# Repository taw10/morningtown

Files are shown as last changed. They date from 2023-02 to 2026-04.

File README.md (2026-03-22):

MorningTown: A silent alarm clock
=================================

Description
-----------

MorningTown is a silent alarm clock system based on a Raspberry Pi Pico.

At 7:15am, it lights a single green LED.  At 8am, it additionally lights a red
LED.  Around midday, it turns them both off.  Apart from an over-engineered
configuration system, it does literally nothing else.

Why???
------

You are supposed to get out of bed if you wake up and see the green light, or
perhaps doze until you see the red light as well.  If no lights are on, go
back to sleep.

Huh??
-----

[Awareness of the exact time is bad for your sleep](https://www.techradar.com/health-fitness/mattresses/clock-watching-could-be-killing-your-sleep-why-clocks-have-no-place-in-the-bedroom).

If you're having trouble getting to sleep, seeing the time will add stress
and make it even harder to sleep.  Similarly, knowing that your alarm will go off
shortly can prevent you from relaxing in the morning, and grabbing a valuable
few minutes' extra sleep.

MorningTown reduces information about the time down to a simple signal to say
either "Go back to sleep" or "Get up if you're ready".

In contrast to a clock radio or "artificial sunrise" lamp, there is no danger
of disturbing any other beings who share the room and may run on different
schedules.

I still have a number of questions
----------------------------------

Obviously, you should set an audible alarm clock for important wake-up calls.

Hardware
--------

The Pi Pico's real-time clock loses time when power is removed, so MorningTown
needs either a separate battery-backed RTC module, or to synchronise itself
using NTP on each startup.

### PCB with real-time clock and battery backup

Send the circuit board design in the `pcb` folder
([KiCad](https://www.kicad.org/) format) to your manufacturer of choice.
I have been using [Aisler](https://aisler.net/).

### Cheap and cheerful option

Solder red and green LEDs to GPIOs 22 and 21 respectively of a Raspberry Pi
Pico W, each with a 1.5 kOhm series resistor (you won't need much brightness).
There is a ground pad conveniently placed between these two pins.

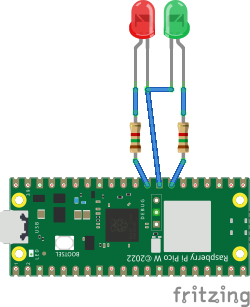
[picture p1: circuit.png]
Circuit diagram
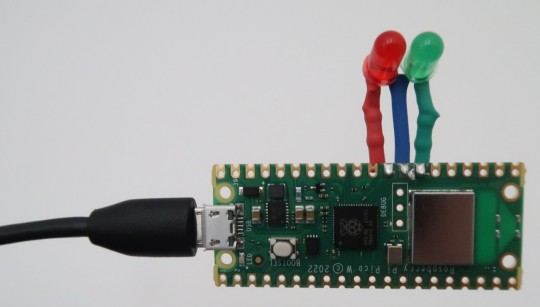
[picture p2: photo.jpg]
    

You can use other GPIOs if you prefer - see below for configuration
instructions.

Firmware
--------

Edit `compile` to set the path to the [Pico SDK](https://github.com/raspberrypi/pico-sdk),
as well as your WLAN name and password if you are using a Pico W.

The changeover days for daylight savings are hard-coded for Europe (the last
Sundays of March and October).  Unfortunately, a full local time library is far
too big to fit on the Pico, so you will have to figure out the logic yourself
for other time zones.

Run `compile`, then copy `build/morningtown.uf2` to the Pico.

Operation
---------

Connect the Pico to any USB power supply.

When the (optional) test button is held, the LEDs indicate as follows:
* Red: NTP synchronised if applicable, otherwise always on.
* Green: RTC time OK (regardless of source).
* Board LED: WLAN connected if applicable, otherwise always on.

Licence
-------

MorningTown is based on a heavily modified version of one of the Pico SDK
examples (picow-ntp-client), copyright (c) 2022 Raspberry Pi (Trading) Ltd.,
under the BSD 3-clause licence.

MorningTown is free software: you can redistribute it and/or modify it under the
terms of the GNU General Public License as published by the Free Software
Foundation, either version 3 of the License, or (at your option) any later
version.

MorningTown is distributed in the hope that it will be useful, but WITHOUT ANY
WARRANTY; without even the implied warranty of MERCHANTABILITY or FITNESS FOR A
PARTICULAR PURPOSE.  See the GNU General Public License for more details.

You should have received a copy of the GNU General Public License along with
MorningTown.  If not, see <http://www.gnu.org/licenses/>.

About the name
--------------

It's like a railway signal for your sleep:

> Somewhere there is sunshine  
> Somewhere there is day  
> Somewhere there is Morning town  
> Many miles away

- [Malvina Reynolds](https://en.wikipedia.org/wiki/Morningtown_Ride)

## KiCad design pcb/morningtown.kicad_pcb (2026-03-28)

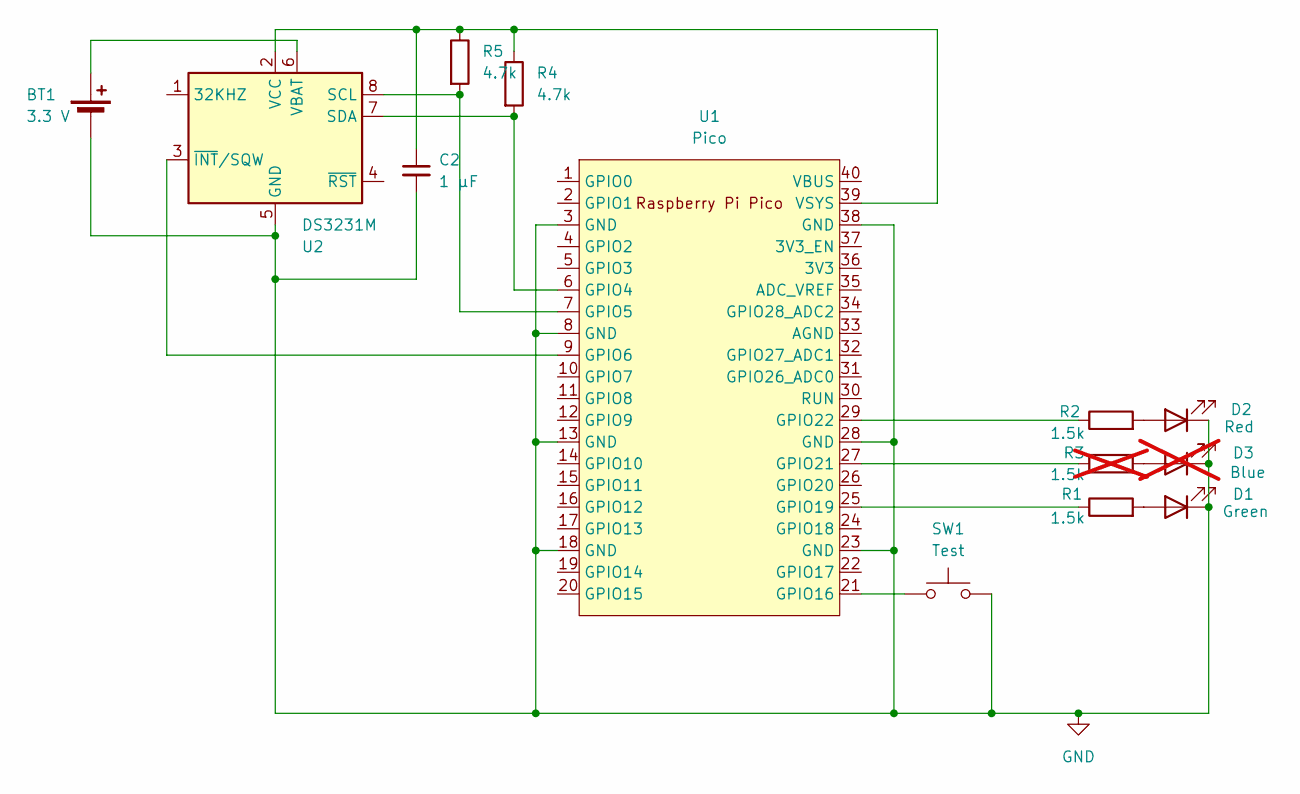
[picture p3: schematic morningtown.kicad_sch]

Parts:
BT1: 3.3 V; BatteryHolder_Keystone_3001_1x12mm
C2: 1 µF; C_0805_2012Metric_Pad1.18x1.45mm_HandSolder
D1: Green; LED_D5.0mm
D2: Red; LED_D5.0mm
D3: Blue; LED_D3.0mm; not fitted
R1, R2: 1.5k; R_0805_2012Metric_Pad1.20x1.40mm_HandSolder
R3: 1.5k; R_0805_2012Metric_Pad1.20x1.40mm_HandSolder; not fitted
R4, R5: 4.7k; R_0805_2012Metric_Pad1.20x1.40mm_HandSolder
SW1: Test; SW_PUSH_6mm
U1: Pico; RPi_Pico_W
U2: DS3231M; SOIC-8_3.9x4.9mm_P1.27mm

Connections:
GND: BT1.2 (-), C2.2, D1.1 (K), D2.1 (K), D3.1 (K), SW1.2, U1.3 (GND), U1.8 (GND), U1.13 (GND), U1.18 (GND), U1.23 (GND), U1.28 (GND), U1.38 (GND), U2.5 (GND)
unnamed: BT1.1 (+), U2.6 (VBAT)
unnamed: D1.2 (A), R1.2
unnamed: D2.2 (A), R2.2
unnamed: D3.2 (A), R3.2
unnamed: R4.2, U1.6 (GPIO4), U2.7 (SDA)
unnamed: R5.2, U1.7 (GPIO5), U2.8 (SCL)
unnamed: U1.9 (GPIO6), U2.3 (~INT/SQW)
unnamed: SW1.1, U1.21 (GPIO16)
unnamed: R1.1, U1.25 (GPIO19)
unnamed: R3.1, U1.27 (GPIO21)
unnamed: R2.1, U1.29 (GPIO22)
unnamed: C2.1, R4.1, R5.1, U1.39 (VSYS), U2.2 (VCC)

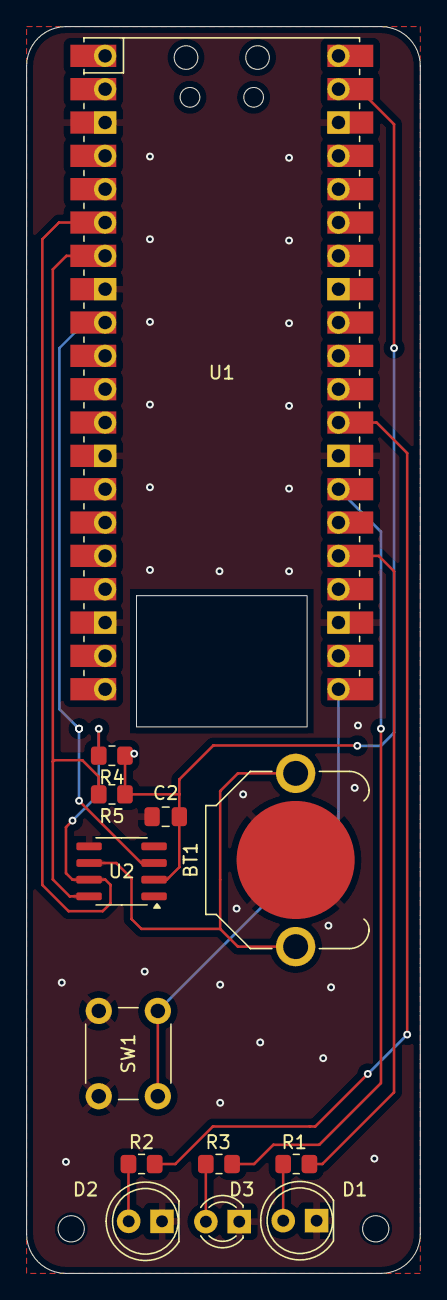
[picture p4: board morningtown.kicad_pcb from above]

Board: 2 copper layers, 30.0 x 95.0 mm, 15 parts (0 on the bottom side), 13 nets.

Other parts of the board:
FrontL: MountingHole_2mm
FrontR: MountingHole_2mm

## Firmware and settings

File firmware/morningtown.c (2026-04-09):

/*
 * morningtown.c
 *
 * Silent alarm clock
 *
 * Copyright © 2023 Thomas White <taw@physics.org>
 *
 * This file is part of MorningTown
 *
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
 */

#include <pico/stdlib.h>
#include <hardware/rtc.h>
#include <hardware/watchdog.h>
#include <hardware/pwm.h>
#include <time.h>
#include <stdio.h>

#ifdef PICO_W
#include <pico/cyw43_arch.h>
#endif

#include "ntp_client.h"
#include "terminal.h"
#include "ds3231.h"
#include "settings.h"

#define LED_BLUE 21
#define TEST_BUTTON 16

static void check_clock(int *pre_wake, int *wake_now)
{
    int32_t dstoffs;
    datetime_t t = {0};

    if ( ds3231_get_datetime(&t) ) {
        rtc_get_datetime(&t);
    }

    dstoffs = settings.utc_offset + dst(t);

    if ( t.hour >= settings.clear_hour-dstoffs ) {
        *pre_wake = 0;
        *wake_now = 0;

    } else if ( (t.hour >= settings.late_hour-dstoffs) && (t.min >= settings.late_min) ) {
        *pre_wake = 0;
        *wake_now = 1;

    } else if ( (t.hour >= settings.morning_hour-dstoffs) && (t.min >= settings.morning_min) ) {
        *pre_wake = 1;
        *wake_now = 0;

    } else {
        *pre_wake = 0;
        *wake_now = 0;
    }

}


static void setup_pwm(int pin)
{
    gpio_set_function(pin, GPIO_FUNC_PWM);
    uint slice_num = pwm_gpio_to_slice_num(pin);
    pwm_config config = pwm_get_default_config();
    pwm_config_set_clkdiv(&config, 4.f);
    pwm_init(slice_num, &config, true);
    pwm_set_gpio_level(pin, 0);
}


static void set_board_led(int level)
{
    #ifdef PICO_W
    cyw43_arch_gpio_put(CYW43_WL_GPIO_LED_PIN, level);
    #else
    gpio_put(PICO_DEFAULT_LED_PIN, level);
    #endif
}


int main()
{
    NTP_T *ntp_state;
    int last_conn, countdown;
    int pre_wake = 0;
    int wake_now = 0;
    int time_ok = 0;

    const int brightness = 65535;

    stdio_init_all();
    printf("MorningTown initialising\n");

#ifdef PICO_W
    cyw43_arch_init();
    cyw43_arch_enable_sta_mode();
#else
    gpio_init(PICO_DEFAULT_LED_PIN);
    gpio_set_dir(PICO_DEFAULT_LED_PIN, GPIO_OUT);
#endif

    watchdog_enable(0x7fffff, 1);
    rtc_init();
    ds3231_init();

    /* Board LED shows we're alive */
    set_board_led(1);

    gpio_init(TEST_BUTTON);
    gpio_set_dir(TEST_BUTTON, GPIO_IN);
    gpio_pull_up(TEST_BUTTON);

    settings_read();

    setup_pwm(settings.morning_pin);
    setup_pwm(settings.late_pin);
    setup_pwm(LED_BLUE);

    pwm_set_gpio_level(LED_BLUE, brightness);

    if ( !set_picortc_from_ds3231() ) {
        time_ok = 1;
    }

    /* Red light indicates DS3231 */
    sleep_ms(500);
    if ( ds3231_found() ) {
        pwm_set_gpio_level(settings.late_pin, brightness);
    }

    if ( ds3231_osf_set() ) {
        int i;
        for ( i=0; i<25; i++ ) {
            pwm_set_gpio_level(settings.late_pin, brightness);
            sleep_ms(100);
            pwm_set_gpio_level(settings.late_pin, 0);
            sleep_ms(100);
        }
    }

    /* Green light indicates RP2040 RTC */
    sleep_ms(500);
    if ( rtc_running() ) {
        pwm_set_gpio_level(settings.morning_pin, brightness);
    }

    /* Wait, then turn everything off */
    sleep_ms(2000);
    set_board_led(0);
    pwm_set_gpio_level(settings.morning_pin, 0);
    pwm_set_gpio_level(settings.late_pin, 0);
    pwm_set_gpio_level(LED_BLUE, 0);

    Terminal *trm = terminal_init();

    ntp_state = ntp_init();
    last_conn = 20000;
    countdown = 100;
    while (1) {

        watchdog_update();

#ifdef PICO_W
        int st = cyw43_wifi_link_status(&cyw43_state, CYW43_ITF_STA);

        if ( (st != CYW43_LINK_JOIN) && (last_conn > 10000) ) {
            cyw43_arch_wifi_connect_async(WIFI_SSID,
                    WIFI_PASSWORD,
                    CYW43_AUTH_WPA2_AES_PSK);
            printf("connecting to wifi...\n");
            last_conn = 0;
        }
#endif

        if ( ntp_ok(ntp_state) ) time_ok = 1;

        /* Check clock every 10 seconds */
        countdown--;
        if ( countdown == 0 ) {
            if ( time_ok ) check_clock(&pre_wake, &wake_now);
            countdown = 100;
        }

        /* Determine the LED status */
        if ( gpio_get(TEST_BUTTON) == 0 ) {
            /* Button pressed */
            pwm_set_gpio_level(settings.morning_pin, (time_ok && rtc_running())?brightness:0);
            pwm_set_gpio_level(settings.late_pin, ntp_ok(ntp_state)?brightness:0);
#ifdef PICO_W
            set_board_led(st == CYW43_LINK_JOIN);
#else
            set_board_led(1);
#endif
        } else {
            /* Normal operation */
            pwm_set_gpio_level(settings.morning_pin, (pre_wake||wake_now)?brightness:0);
            pwm_set_gpio_level(settings.late_pin, wake_now?brightness:0);
            set_board_led(0);
        }

        last_conn += 1;
#ifdef PICO_W
        cyw43_arch_poll();
#endif
        terminal_poll(trm);
        if ( stdio_usb_connected() ) {
            set_board_led(1);
            sleep_ms(10);
        } else {
            set_board_led(0);
            sleep_ms(100);
        }

    }
}

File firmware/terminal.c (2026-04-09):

/*
 * terminal.c
 *
 * Copyright © 2024 Thomas White <taw@physics.org>
 *
 * This file is part of MorningTown
 *
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
 */

#include <pico/stdlib.h>
#include <hardware/rtc.h>
#include <stdio.h>
#include <string.h>

#include "ds3231.h"
#include "terminal.h"
#include "settings.h"

struct terminal
{
    char c[256];
    int nchar;
};

struct terminal terminal_data;


static void set_pins(const char *str)
{
    int morning, late;
    if ( sscanf(str, "%i %i", &morning, &late) == 2 ) {
        settings.morning_pin = morning;
        settings.late_pin = late;
    } else {
        printf("Syntax: leds <morning> <late>\n");
        printf("Default: leds 19 22\n");
    }
}


static void set_wake(const char *str)
{
    int hours, mins;
    if ( sscanf(str, "%i %i", &hours, &mins) == 2 ) {
        settings.morning_hour = hours;
        settings.morning_min = mins;
    } else {
        printf("Syntax: wake <hh> <mm>\n");
        printf("Default: wake 7 15\n");
    }
}


static void set_rise(const char *str)
{
    int hours, mins;
    if ( sscanf(str, "%i %i", &hours, &mins) == 2 ) {
        settings.late_hour = hours;
        settings.late_min = mins;
    } else {
        printf("Syntax: rise <hh> <mm>\n");
        printf("Default: wake 8 0\n");
    }
}


static void set_utc_offset(const char *str)
{
    int hours;
    if ( sscanf(str, "%i", &hours) == 1 ) {
        settings.utc_offset = hours;
    } else {
        printf("Syntax: tz <hours>\n");
        printf("Default (for CET/CEST): tz 1\n");
    }
}


static void set_clear_time(const char *str)
{
    int hours;
    if ( sscanf(str, "%i", &hours) == 1 ) {
        settings.clear_hour = hours;
    } else {
        printf("Syntax: clear <hours>\n");
        printf("Default: clear 12\n");
    }
}


static void set_clock(const char *str)
{
    int dow, d, mon, y, h, m, s;
    if ( sscanf(str, "%i %i %i %i %i %i %i", &dow, &d, &mon, &y, &h, &m, &s) == 7 ) {

        datetime_t t;
        bool r;

        printf("OK %i-%i-%i (%i), %i:%i:%i\n", d, mon, y, dow, h, m, s);

        t.year = y;
        t.month = mon;
        t.day = d;
        t.dotw = dow;
        t.hour = h;
        t.min = m;
        t.sec = s;
        if ( !rtc_set_datetime(&t) ) {
            printf("RTC set failed\n");
        } else {
            printf("OK!\n");
        }

    } else {
        printf("Syntax: set <weekday> <day> <mon> <yyyy> <hour> <min> <sec>\n");
        printf("Note: Time should be in UTC\n");
        printf("<weekday> = 0..6 for Sunday..Saturday\n");
    }
}


static const char *dotw_pico(int n)
{
    switch (n) {
        case 0 : return "Sunday";
        case 1 : return "Monday";
        case 2 : return "Tuesday";
        case 3 : return "Wednesday";
        case 4 : return "Thursday";
        case 5 : return "Friday";
        case 6 : return "Saturday";
        default : return "UNKNOWN";
    }
}


static void print_datetime()
{
    datetime_t t = {0};
    int r;
    r = rtc_get_datetime(&t);
    if ( r ) {
        printf("Pico RTC date/time (UTC): %i-%i-%i (%s)  %i:%i:%i\n",
               t.day, t.month, t.year, dotw_pico(t.dotw), t.hour, t.min, t.sec);
    } else {
        printf("Pico RTC not running.\n");
    }
    printf("Offset to local time: %i + %i\n", settings.utc_offset, dst(t));
}


static void run_command(struct terminal *trm)
{
    trm->c[trm->nchar] = '\0';

    if ( trm->nchar == 0 ) return;

    if ( strcmp(trm->c, "ds") == 0 ) {
        ds3231_status();

    } else if ( strcmp(trm->c, "tt") == 0 ) {
        print_datetime();

    } else if ( strncmp(trm->c, "set ", 4) == 0 ) {
        set_clock(trm->c+4);

    } else if ( strcmp(trm->c, "setds") == 0 ) {
        set_ds3231_from_picortc();

    } else if ( strcmp(trm->c, "osf") == 0 ) {
        ds3231_reset_osf();

    } else if ( strcmp(trm->c, "load") == 0 ) {
        settings_read();

    } else if ( strcmp(trm->c, "save") == 0 ) {
        settings_write();

    } else if ( strcmp(trm->c, "settings") == 0 ) {
        settings_show();

    } else if ( strncmp(trm->c, "leds ", 5) == 0 ) {
        set_pins(trm->c+5);

    } else if ( strncmp(trm->c, "wake ", 5) == 0 ) {
        set_wake(trm->c+5);

    } else if ( strncmp(trm->c, "rise ", 5) == 0 ) {
        set_rise(trm->c+5);

    } else if ( strncmp(trm->c, "tz ", 3) == 0 ) {
        set_utc_offset(trm->c+3);

    } else if ( strncmp(trm->c, "clear ", 6) == 0 ) {
        set_clear_time(trm->c+6);

    } else if ( strcmp(trm->c, "help") == 0 ) {
        printf("Commands:\n");
        printf("  help     : Show this help message\n");
        printf("  tt       : Show Pico RTC date/time\n");
        printf("  set      : Set UTC date/time\n");
        printf("  ds       : Show DS3231 date/time and status\n");
        printf("  setds    : Set DS3231 from Pico RTC\n");
        printf("  osf      : Reset DS3231 stop flag\n");
        printf("  load     : Load settings\n");
        printf("  save     : Save settings\n");
        printf("  settings : Show settings\n");
        printf("  leds     : Set wake LED pin assignments\n");
        printf("  wake     : Set waking time (green)\n");
        printf("  rise     : Set rise/late time (red)\n");
        printf("  tz       : Set UTC offset\n");
        printf("  clear    : Set wake LED reset time\n");

    } else {
        printf("Command not recognised.  Try 'help'\n");
    }

}


void terminal_poll(Terminal *trm)
{
    int i;

    i = getchar_timeout_us(0);
    if ( i == PICO_ERROR_TIMEOUT ) return;
    if ( i == 0 ) return;

    if ( (i == 13) || (i == 10) ) {
        printf("\n");
        run_command(trm);
        printf("\nmorningtown> ");
        trm->nchar = 0;
        return;
    }

    if ( i == 21 ) {
        trm->nchar = 0;
        printf("\r                                                       \rmorningtown> ");
        return;
    }

    if ( i == 8 ) {
        printf("%c %c", i, i);
        trm->nchar--;
        return;
    }

    if ( trm->nchar == 256 ) return;
    trm->c[trm->nchar++] = i;
    printf("%c", i);
}


Terminal *terminal_init()
{
    struct terminal *trm = &terminal_data;
    trm->nchar = 0;
    printf("\n\nmorningtown> ");
    return trm;
}

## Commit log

2023-02-19 Add circuit diagram
2023-02-26 Add test button
2023-02-27 Test button should not have priority over clock LEDs
2023-03-02 Use pico_cyw43_arch_lwip_poll
    So little can be done in lwIP callbacks with the background driver, we
    end up polling anyway. So we might as well poll the driver directly,
    and be able to do more in the callbacks.
2023-07-02 Slow down wifi associations, use LEDs less
    First, trying to re-connect to wifi every 10 seconds is way too fast.
    Second, if there's an error, keep quiet about it unless the button is
    pushed. The RTC will probably not drift too far...!
    [morningtown.c]
2024-12-20 Enable compilation for non-W Pico
2024-12-20 Add parameters for nice PCB
2024-12-20 Add PWM dimming for LEDs
2024-12-21 Get rid of unnecessary printf wrapper
2024-12-23 DS3231: Disable EN32KHZ bit on startup
    We don't use it. It's just wasting power.
2024-12-23 Add command to reset DS3231 Oscillator Stop Flag (OSF)
    This is used to detect if something bad happened to the clock.
    [ds3231.c, terminal.c]
2024-12-23 Report if Pico RTC doesn't seem to be running
    [terminal.c]
2024-12-23 Ignore zero character
    This was preventing the first command from working.
    [terminal.c]
2024-12-23 Add non-W board LED to startup lightshow
2024-12-24 Initial import
    [morningtown.kicad_pcb, morningtown.kicad_sch]
2024-12-29 Fix r1.0 errata
    [morningtown.kicad_pcb, morningtown.kicad_sch]
2025-01-01 Detect DS3231 at runtime
    Doing it at compile time doesn't give any benefit.
    [ds3231.c]
2025-01-01 Fix help message logic
    [terminal.c]
2025-01-07 Switch to SMD resistors and capacitors
    [morningtown.kicad_pcb, morningtown.kicad_sch]
2025-01-09 General tidy-up
    [morningtown.kicad_pcb]
2025-03-03 Slow down I2C communication to DS3231
    The PCB lacks the pull-up resistors needed to go so fast.
2025-03-03 LED fixes
2025-03-03 Fix DST calculation and lies in comments
    [morningtown.c]
2025-03-03 Report if RTC set fails
    [terminal.c]
2026-03-15 Move PCB files to separate folder
    [morningtown.kicad_pcb, morningtown.kicad_sch]
2026-03-15 Update KiCad files to latest version, update errata, add metadata
    [morningtown.kicad_pcb, morningtown.kicad_sch]
2026-03-21 Set LED pin assignments via console/settings
2026-03-22 Fix clear/tz commands and help
    [terminal.c]
2026-03-28 Work on PCB
    [morningtown.kicad_pcb, morningtown.kicad_sch]
2026-04-09 Fix wonky integer types which broke everything
    [morningtown.c]
